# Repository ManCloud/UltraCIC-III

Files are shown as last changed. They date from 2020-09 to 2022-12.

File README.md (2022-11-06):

# UltraCIC-III
This code allows you to create a replacement CIC chip for N64 games that you own on an ATTiny25, ATTiny45 of ATTiny85. 
The original code was written by jesgdev and updated with multi-region support by saturnu. 
I simply extended the version Krikzz created under the name UltraCIC-II to support automatic switching between NTSC and PAL if the console was unable to boot.

# Instructions
- Install avra 
- Assemble the code
  - avra UltraCIC-III.asm -d {MCU}
  - {MCU} must be one of the supported MCUs (attiny25, attiny45 or attiny85)
- Flash the file to your ATTiny 
  - e.g.: "avrdude -p t25 -c usbtiny -U flash:w:UltraCIC-III.hex eeprom:w:UltraCIC-III.hex.eep" for attiny25
- Update fuses
  - e.g.: "avrdude -p t25 -c usbtiny -U lfuse:w:0xc0:m -U hfuse:w:0xdf:m" for attiny25
  
# More Information
[Sources for UltraCIC-II](https://web.archive.org/web/20180701050159/https://krikzz.com/pub/support/everdrive-64/ultracic2/)

[Multi-region patch information](https://krikzz.com/forum/index.php?topic=3450.0)

[Assembly guide by perkinsb1024](https://bitwise.bperki.com/2019/01/12/repairing-an-n64-cartridge-without-blowing-in-it/)

# PCB
see [pcb](pcb/) subfolder

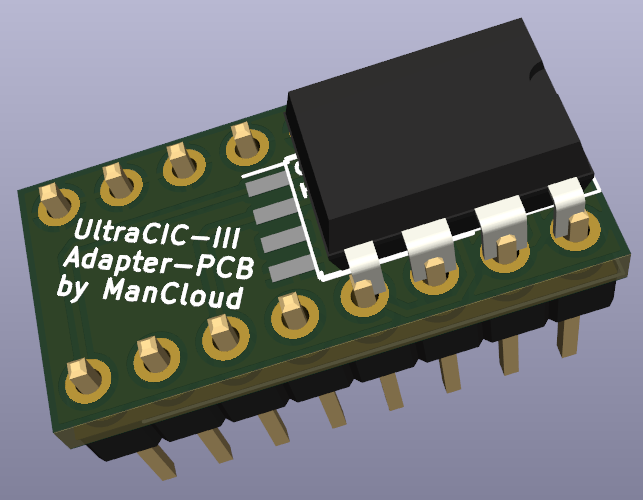
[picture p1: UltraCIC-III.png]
Preview of UltraCIC-III


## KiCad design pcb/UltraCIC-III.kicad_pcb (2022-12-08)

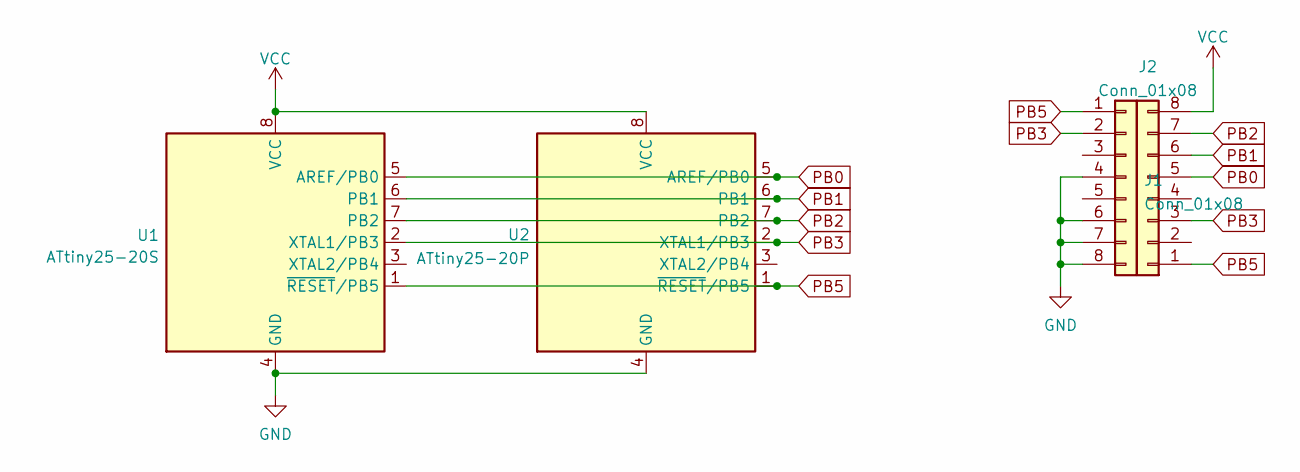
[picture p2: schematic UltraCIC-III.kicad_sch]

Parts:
J1, J2: Conn_01x08; PinHeader_1x08_P2.54mm_Vertical
U1: ATtiny25-20S; SOP-8-Wide
U2: ATtiny25-20P; DIP-8_W7.62mm

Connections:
GND: J1.4, J1.6, J1.7, J1.8, U1.4 (GND), U2.4 (GND)
PB0: J2.5, U1.5 (AREF/PB0), U2.5 (AREF/PB0)
PB1: J2.6, U1.6 (PB1), U2.6 (PB1)
PB2: J2.7, U1.7 (PB2), U2.7 (PB2)
PB3: J1.2, J2.3, U1.2 (XTAL1/PB3), U2.2 (XTAL1/PB3)
PB5: J1.1, J2.1, U1.1 (~RESET/PB5), U2.1 (~RESET/PB5)
VCC: J2.8, U1.8 (VCC), U2.8 (VCC)

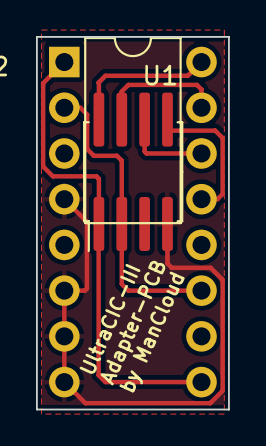
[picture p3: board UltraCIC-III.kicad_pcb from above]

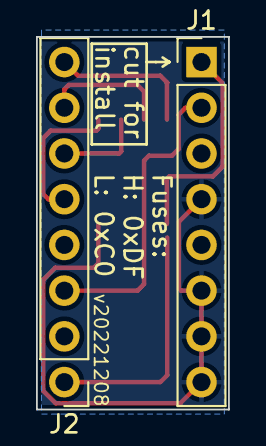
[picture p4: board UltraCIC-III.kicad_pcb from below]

Board: 2 copper layers, 10.7 x 20.7 mm, 4 parts (2 on the bottom side), 7 nets.

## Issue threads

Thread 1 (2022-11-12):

Doesn't boot up after cartridge upgrade

martis2580, 2022-11-12:
Cartridge - Mario Kart (Japan);
Original CIC chip - NUS 6102;
UltraCIC-III asembler code was compiled to hex by the Microchip Studio software;
hex file was flashed to attiny25;

set up:
fuse bit - low: 0xc0 and high: 0xdf
code configuration:
.equ CIC_TYPE=0b00    ;6102/7101 was choosen
.db 0x08   ;set PAL as inital region was choosen

ManCloud, 2022-11-12:
Afaik only avra is able to produce runnable code.

There are some assembler statements that are not implemented in the other assemblers.

Please recompile with avra again and tell me if the issue resides.

Thanks 👍

martis2580, 2022-11-12:
Thank You for your prompt answer. OK I will try.
Another one thing, according to this link https://bitwise.bperki.com/2019/01/12/repairing-an-n64-cartridge-without-blowing-in-it/
"Repairing An N64 Cartridge (Without Blowing In It!)" author said that
"chip cannot be (easily) programmed again" due to -U lfuse:w:0xc0:m.
So what is way to reflash attiny? Please fix me is true that every time is needes new Attiny?

ManCloud, 2022-11-13:
That depends on how you Programm it.
If you're using an Arduino you can simply add a clk-line to you setup.

Cause the attiny now depends on an external clk that most programmers do not provide.

Have a look at the Sanni Cartreader wiki for details: https://github.com/sanni/cartreader/wiki/Reflashing-a-N64-Repro

But if you're using something "professional" like a TL866II-Plus (or similar): they are capable to apply the needed clocks and you'd have no trouble.

Last thing possible would be to program it while being in the N64 to have a clk source... But I wouldn't recommend this.

martis2580, 2022-11-14:
Thank you  for your detail answer.

martis2580, 2022-11-14:
Can you recommend what kind of linux to used to set up hex file with avra. Thanks in advance.

martis2580, 2022-11-15:
**The secondary try- - - - > not successful**
Please look to installation extracts below.

_UltraCIC II code was recompiled:
cd UltraCIC-II-master
~/UltraCIC-II-master avra UltraCIC_t25.asm
AVRA: advanced AVR macro assembler (version 1.4.2)
Pass 1...
Pass 2...
tn45def.inc(44) : PRAGMA PARTINC directive currently ignored
tn45def.inc(48) : PRAGMA AVRPART directive currently ignored
tn45def.inc(53) : PRAGMA AVRPART directive currently ignored
tn45def.inc(54) : PRAGMA AVRPART directive currently ignored
tn45def.inc(646) : PRAGMA AVRPART directive currently ignored
tn45def.inc(647) : PRAGMA AVRPART directive currently ignored
tn45def.inc(648) : PRAGMA AVRPART directive currently ignored
tn45def.inc(649) : PRAGMA AVRPART directive currently ignored
done

Assembly complete with no errors.
Segment usage:
   Code      :       679 words (1358 bytes)
   Data      :         0 bytes
   EEPROM    :         0 bytes_

----------------
**After that was programm it to attiny25:**

_avrdude -B 4.0 -p t25 -c usbasp -e -U flash:w:UltraCIC_t25.hex                             

avrdude: set SCK frequency to 187500 Hz
avrdude: AVR device initialized and ready to accept instructions

Reading | ################################################## | 100% 0.01s

avrdude: Device signature = 0x1e9108 (probably t25)
avrdude: erasing chip
avrdude: set SCK frequency to 187500 Hz
avrdude: reading input file "UltraCIC_t25.hex"
avrdude: input file UltraCIC_t25.hex auto detected as Intel Hex
avrdude: writing flash (1358 bytes):

Writing | ################################################## | 100% 1.08s

avrdude: 1358 bytes of flash written
avrdude: verifying flash memory against UltraCIC_t25.hex:
avrdude: load data flash data from input file UltraCIC_t25.hex:
avrdude: input file UltraCIC_t25.hex auto detected as Intel Hex
avrdude: input file UltraCIC_t25.hex contains 1358 bytes
avrdude: reading on-chip flash data:

Reading | ################################################## | 100% 0.63s

avrdude: verifying ...
avrdude: 1358 bytes of flash verified

avrdude: safemode: Fuses OK (E:FF, H:DF, L:62)

avrdude done.  Thank you.

    ~/UltraCIC-II-master  avrdude -B 4.0 -p t25 -c usbasp -U lfuse:w:0xc0:m -U hfuse:w:0xdf:m                                 ✔

avrdude: set SCK frequency to 187500 Hz
avrdude: AVR device initialized and ready to accept instructions

Reading | ################################################## | 100% 0.01s

avrdude: Device signature = 0x1e9108 (probably t25)
avrdude: reading input file "0xc0"
avrdude: writing lfuse (1 bytes):

Writing | ################################################## | 100% 0.01s

avrdude: 1 bytes of lfuse written
avrdude: verifying lfuse memory against 0xc0:
avrdude: load data lfuse data from input file 0xc0:
avrdude: input file 0xc0 contains 1 bytes
avrdude: reading on-chip lfuse data:

Reading | ################################################## | 100% 0.00s

avrdude: verifying ...
avrdude: 1 bytes of lfuse verified
avrdude: reading input file "0xdf"
avrdude: writing hfuse (1 bytes):

Writing | ################################################## | 100% 0.00s

avrdude: 1 bytes of hfuse written
avrdude: verifying hfuse memory against 0xdf:
avrdude: load data hfuse data from input file 0xdf:
avrdude: input file 0xdf contains 1 bytes
avrdude: reading on-chip hfuse data:

Reading | ################################################## | 100% 0.00s

avrdude: verifying ...
avrdude: 1 bytes of hfuse verified

avrdude: safemode: Fuses OK (E:FF, H:DF, L:C0)

avrdude done.  Thank you._

What do you think? Maybe Mario kart cartridge pcb is broken? The first my impression when I open the cartridge was positive, because condition is pretty good.

martis2580, 2022-11-22:
Maybe is any idea how solve this issue?

ManCloud, 2023-01-15:
I'm a little confused... You aren't using UltraCIC-III are you?
Cause your file is "UltraCIC_t25.asm", which doesn't even exist in UltraCIC-III...
I can't give you support for something that's not my code

Risc2m, 2024-08-11:
podrías por favor hacer un tutorial mas detallado de como crear el HEX con avra?

Gracias!

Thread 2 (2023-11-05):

Correct cuts

Radeon91, 2023-11-05:
PCB says that u have to cut Pin1, but there is also a box in pin 9, shall we cut both or only pin 1?

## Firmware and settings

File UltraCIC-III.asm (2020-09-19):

.if defined(attiny25)
.include "tn25def.inc"
.message "Build UltraCIC-III for ATtiny25"
.elif defined(attiny45)
.include "tn45def.inc"
.message "Build UltraCIC-III for ATtiny45"
.elif defined(attiny85)
.include "tn85def.inc"
.message "Build UltraCIC-III for ATtiny85"
.else
.warning "no suitable MCU specified"
.endif




;UltraCIC-III.asm
;N64 CIC clone!
;ATtiny85
;
;Author: jesgdev
;Credits:
;   ccsfp221-kammerstetter.pdf - Thanks to those authors!
;   KRIKzz - 710x dumps and testing.
;   saturnu - UltraCIC-II mix mode features.
;   ManCloud - UltraCIC-III - auto region change
;
; How-To change region: insert into console. If it doesn't boot, power off and power on again. Region is changed
;
;Pinout(references(direct, pad,  etc..) refer to the CIC footprint on a typical cart board).
;1: Reset, this is the actual /RST pin of AVR.  Pad is VCC.  Lift and jump or disconnect VCC from pad.
;2: CLKIN, unused pad, jumper to 11(cic pinout), cart edge #19
;3: ??, unused pad
;4: GND, unused pad, jump to nearby pad(last 3 in row are GND)
;5: CICPIN2_2, direct, tied to GND(always?)
;6: CICPIN2_1, direct, cart edge #43 (Data Clock)
;7: CICPIN2_0, direct, cart edge #18 (Data I/O)
;8: VCC, direct
;
;1 cic clock = 2 AVR clocks.  Clocks given in code are avr clocks.
;
;Programming the AVR:
;Fuses:
;/Reset enabled
;Disable debug wire
;disable watchdog
;disable bod(probably doesn't matter?)
;No clock div(default is div8, make sure to disable!)
;Fastest startup, external clock
;SUT=00
;CKSEL=0000
;
;tiny85
;LOW: 0xc0
;high: 0xdf


;------------------------------------------------
;Choose the CIC type(pick one):
;------------------------------------------------
.equ CIC_TYPE=0b00    ;6102/7101
;.equ CIC_TYPE=0b01    ;6103/7103
;.equ CIC_TYPE=0b10    ;6106/7106
;.equ CIC_TYPE=0b11    ;6101/7102

;------------------------------------------------

;registers
.def const0=r0
.def const1=r1
.def constF=r15
.def areg=r16           ;cic a register
.def xreg=r17           ;cic x register
.def flags=r18          ;bit flags, descriptions below.
.def scr0=r22           ;scratch registers(scr2 & scr3 must be a 16bit pair)
.def scr1=r23
.def scr2=r24           ;LSB of pair
.def scr3=r25           ;MSB of pair

;ram, need 64 consecutive bytes...watch the stack!
.equ CICRAM_START=0x80

;I/O
.equ CICPINS=PINB
.equ CICPORT=PORTB
.equ CICDDR=DDRB
.equ CICPIN0=PINB2      ;cic port2 pin0
.equ CICPIN1=PINB1      ;cic port2 pin1
.equ CICPIN2=PINB0      ;cic port2 pin2

;Flags(bit location of flag in flags register,  do not change these values)
.equ FLAG_x105_MODE=0           ;0=x10x, 1=x105
.equ FLAG_M0112_M0132_MODE=1    ;m0112 mode(see method for use)
.equ FLAG_710x_MODE=2           ;0=610x, 1=710x

.cseg
.org 0x00
    rjmp reset

.org OVF0addr
    rjmp isr_tim0_ov

reset:

    ;ATtiny85 reset delay=14clk

    ;device setup, adapt as needed for device
    ;default CIC pins to input with pullup
    nop
    ldi scr0, 0
    out DDRB, scr0          ;inputs
    ldi scr0, 0xFF
    out PORTB, scr0         ;with pullup
    ldi scr0, 0x0B
    out PRR, scr0           ;power reduction - all but TIMER0
    ldi scr0, 0x80
    out ACSR, scr0          ;comparator disable
    ldi scr0, LOW(RAMEND)   ;STACK!  Make sure SPH is not needed for the part
    out SPL, scr0

    ;setup death timer
    ldi scr0, 0x05
    out TCCR0B, scr0    ;prescaler 1024
    LDI scr0, 0x02
    OUT TIMSK, scr0     ;enable TIMER0 overflow interrupt
    ;rjmp ucDeath

    ;setup registers, memory, etc..
    ldi scr0, 0
    mov const0, scr0
    ldi scr0, 1
    mov const1, scr0
    ldi scr0, 0x0F
    mov constF, scr0
    ldi YH, 0
    ldi YL, CICRAM_START
    mov areg, const0
    mov flags, const0
    mov xreg, const0
    std Y+2, const0     ;CICs seem to use this unitialzed?
    std Y+3, const0     ;CICs seem to use this unitialzed?


    rcall EE_READ

    ;setup key address
    in scr0, EEDR
    andi scr0, 0x08
    sbrc scr0, 3
    sbr flags, (1 << FLAG_710x_MODE)
    ;sbrc scr0, 2
    ;sbr flags, (1 << FLAG_x105_MODE)
    nop
    ori flags, (1 << FLAG_x105_MODE)
    ori scr0, CIC_TYPE
    lsl scr0
    lsl scr0
    lsl scr0
    ldi ZH, HIGH(CIC_KEY_DATA * 2)
    ldi ZL, LOW(CIC_KEY_DATA * 2)
    add ZL, scr0
    adc ZH, const0

    ;79 ticks total(based on guesswork, up to 82 seems fine, signals match best @ 79) TODO: check real ticks consumed

;----------------------
; CIC implementation. |
;----------------------

    ;00:00 - 00:05(12clk)
cic_start:
    nop
    nop
    nop
    rcall ucWaste7
    ldi YL, CICRAM_START + 0x02
    set             ;initial output state

    ;00:06 - 00:0E(mode0=10clk, mode1=12clk or death!)
    sbr flags, (1 << FLAG_M0112_M0132_MODE)
    ;sbis CICPINS, CICPIN2
    nop
    rjmp cic_start_mode_0
cic_start_mode_1:
    rcall m0112     ;in m0132 mode
    cbr flags, (1 << FLAG_M0112_M0132_MODE)
    nop
    nop
    nop
    brcs cic_start_mode_all
    rjmp ucDeath
cic_start_mode_0:
    ldi areg, 0
    clt             ;initial output state
    cbr flags, (1 << FLAG_M0112_M0132_MODE)
    rcall m0112
    ;00:0F - 00:14(12clk)
cic_start_mode_all:
    clt
    sbrc flags, FLAG_710x_MODE
    set
    rcall m0106_skip2       ;initial handshake, send (0 for 610x, 1 for 710x)
    clt
    rcall m0106     ;0
    set
    rcall m0106     ;1

    ;00:15-00:16(446clk, call to 03:00) + 00:17 - 00:19(6clk), (452clk total)
    ;Loads key from Bm=4 to 0:C-0:F in ram
    ldi YL, CICRAM_START + 0x0C
    ldi scr3, 2
    rcall ucLoadFromRom     ;(2itr * 14) + 7 = 35 ticks
    ldi scr3, 134
    rcall ucWasteTicks      ;409 ticks
    rcall m022F
    ldi YL, CICRAM_START + 0x0A     ;m022F screws the pointer, reset it.
    nop
    sei

    ;00:1A - 00:1D(8clk per iteration)
cic_start_commloop1:
    nop
    rcall m020F
    cli
    nop
    add YL, const1
    brhc cic_start_commloop1
    nop

    ;00:1E-00:1F(call to 03:06)
    ;Loads key from Bm=5-7 to 0:4-0:F in ram(644clk)
    dec YL                          ;backup one and store the value at 0:F for later
    ld areg, Y
    ldi YL, CICRAM_START + 0x04
    ldi scr3, 6
    rcall ucLoadFromRom             ;(6itr * 14) + 7 = 91 ticks
    ldi scr3, 180
    rcall ucWasteTicks              ;547 ticks

    ;00:20 - 00:26(14clk)
    nop
    rcall m0622     ;uses ram 0:2 unitialized??
    nop
    rcall m0220     ;uses ram 0:3 unitialized??
    nop
    ldi YL, CICRAM_START
    nop
    rcall m0104

    ;00:27 - 00:2A(8clk per iteration)
cic_start_commloop2:
    nop
    rcall m020F
    nop
    add YL, const1
    brhc cic_start_commloop2
    nop

    ;00:2B - 00:2C(4clk)
    nop
    nop
    nop
    nop     ;CIC rom long jumps to 06:00, we just fall into it.

    ;06:00 - 06:1A(392clk)
cic_ram_init:
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

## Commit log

2020-07-28 Update UltraCIC-III.mk
    corrected fuses
2022-11-06 Added PCB Design
    [UltraCIC-III-B_Cu.gbr, UltraCIC-III-B_Mask.gbr, UltraCIC-III-B_Paste.gbr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]
2022-12-08 Updated PCB
    [UltraCIC-III-B_Cu.gbr, UltraCIC-III-B_Mask.gbr, UltraCIC-III-B_Paste.gbr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]
